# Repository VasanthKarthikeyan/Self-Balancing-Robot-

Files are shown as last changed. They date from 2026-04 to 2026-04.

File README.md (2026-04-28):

# Self-Balancing Robot (ESP32 + MPU6050 + TB6612FNG)

## Overview

This project is a **two-wheeled self-balancing robot** based on the classic **inverted pendulum system**. The robot continuously measures its tilt angle using an **MPU6050 IMU sensor** and applies real-time corrections through a **PID control algorithm** running on an **ESP32 microcontroller**.

By combining sensor fusion, motor control, embedded systems, and mechanical design, this project demonstrates practical implementation of real-time balancing robotics.

---

## Features

* Real-time self-balancing using PID control
* ESP32-based high-speed processing
* MPU6050 accelerometer + gyroscope sensor fusion
* Complementary filter for angle estimation
* TB6612FNG dual motor driver for efficient motor control
* PWM-based motor speed adjustment
* Custom 3D printed chassis design
* Battery-powered portable system
* Expandable for Bluetooth/Wi-Fi remote control

---

## Hardware Components

| Component | Description |
| --- | --- |
| ESP32 DevKit V1 | Main controller board |
| MPU6050 | IMU sensor for tilt measurement |
| TB6612FNG | Dual H-Bridge motor driver |
| N20 DC Gear Motors | Wheel actuation |
| HW-133A / LM2596 | Buck converter for voltage regulation |
| 18650 Li-ion Batteries | Power source |
| 3D Printed Chassis | Structural frame |

---

## System Architecture

### Workflow:

1. MPU6050 reads accelerometer and gyroscope data
2. Complementary filter estimates tilt angle
3. PID controller calculates correction
4. ESP32 generates PWM output
5. TB6612FNG drives motors
6. Wheels move to restore center of gravity

---

## Software Stack

* **Language:** C++ / Arduino Framework
* **Platform:** ESP32
* **Libraries:**

  * Wire.h
  * MPU6050 sensor communication
  * PWM motor control

---

## PID Control

The robot uses:

**PID Output = Kp × Error + Ki × Integral + Kd × Derivative**

### Parameters:

* **Kp** → Immediate correction
* **Ki** → Eliminates steady-state error
* **Kd** → Damping and stability

---

## Mechanical Design

* Fully custom **3D printed upper and lower chassis plates**
* Lightweight design for reduced motor load
* Optimized center of mass for improved balancing
* Modular mounting for electronics and batteries

---

## Challenges Faced

### Hardware:

* Short circuit in motor driver section
* Diagnosed using continuity testing
* Corrected wiring fault for proper motor functionality

### Software:

* Intermittent ESP32 COM port detection issues
* Flashing instability during code upload
* Required debugging of USB and board communication

---

## Future Improvements

* Wheel encoder integration
* Kalman filter implementation
* Bluetooth remote control
* Autonomous navigation
* LiDAR / ultrasonic obstacle detection
* Advanced control systems (LQR / adaptive PID)
* Mobile app integration

---

## Project Applications

* Robotics education
* Control systems experimentation
* Autonomous delivery systems
* Telepresence robots
* Embedded systems learning
* Advanced mechatronics projects

---

## Getting Started

### Requirements:

* Arduino IDE / PlatformIO
* ESP32 Board Package
* MPU6050 Library
* TB6612FNG Driver Wiring

### Steps:

1. Assemble chassis
2. Connect electronics as per schematic
3. Upload firmware to ESP32
4. Tune PID constants
5. Test balance carefully

---

## Results

* Successful motor actuation achieved
* Stable sensor fusion implemented
* Real-time balancing logic operational
* Mechanical prototype completed
* System serves as strong educational and engineering platform

---

## Author

**Vasanth Karthikeyan**
Mechatronics Engineering Student
Focused on robotics, embedded systems, and advanced prototyping.

---

## License

This project is open-source and available for educational and development purposes.

---

## Acknowledgment

This project represents practical integration of:

* Embedded systems
* Control theory
* Mechanical design
* Sensor fusion
* Real-time robotics engineering

It serves as a foundational step toward more advanced autonomous robotic systems.

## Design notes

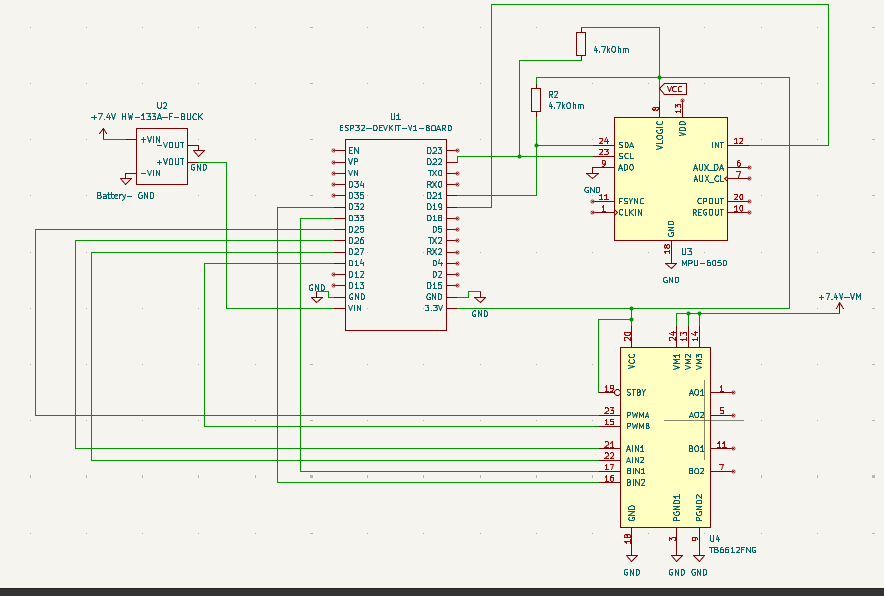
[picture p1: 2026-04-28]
botschematic.png

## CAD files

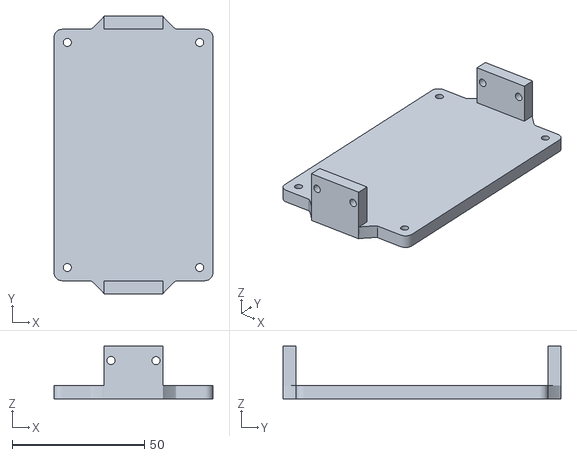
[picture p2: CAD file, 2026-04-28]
lower+body.stl
60.0 x 105.0 x 20.0

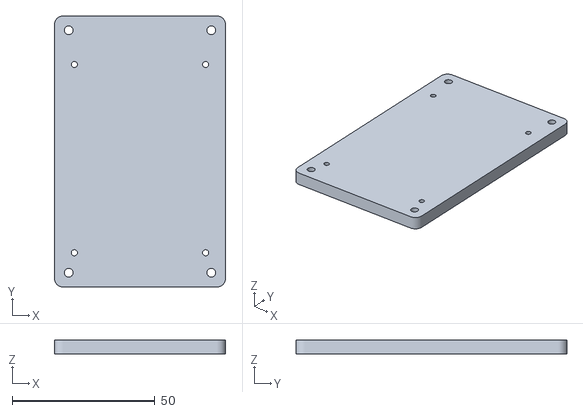
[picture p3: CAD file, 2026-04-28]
upper+body.stl
60.0 x 95.0 x 5.00

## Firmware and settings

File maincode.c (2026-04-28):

#include <Wire.h>

#define SDA_PIN  21
#define SCL_PIN  22
#define MPU_ADDR 0x68

#define ACCEL_SENS  16384.0f
#define GYRO_SENS   131.0f

float angle = 0.0f;
float alpha = 0.98f;
unsigned long lastTime = 0;
// PID
float Kp = 20.0f;
float Ki = 0.0f;
float Kd = 0.8f;
float setpoint   = 3.2f;  // change this to your upright angle
float pidError   = 0.0f;
float prevError  = 0.0f;
float integral   = 0.0f;
float pidOutput  = 0.0f;

// Offsets (calculated during calibration at startup)
float gyroXoffset  = 0.0f;
float accelXoffset = 0.0f;

void writeMPU(uint8_t reg, uint8_t val) {
  Wire.beginTransmission(MPU_ADDR);
  Wire.write(reg);
  Wire.write(val);
  Wire.endTransmission();
}
// Motor A
#define PWMA 25
#define AIN1 26
#define AIN2 27
// Motor B
#define PWMB 14
#define BIN1 33
#define BIN2 32

#define PWM_FREQ  20000
#define PWM_RES   8
#define DEADBAND  30
#define FALL_ANGLE 40.0f

void setMotorA(int spd) {
  if (spd > 0)      { digitalWrite(AIN1, HIGH); digitalWrite(AIN2, LOW); }
  else if (spd < 0) { digitalWrite(AIN1, LOW);  digitalWrite(AIN2, HIGH); spd = -spd; }
  else              { digitalWrite(AIN1, LOW);   digitalWrite(AIN2, LOW); }
  ledcWrite(PWMA, constrain(spd, 0, 255));
}

void setMotorB(int spd) {
  if (spd > 0)      { digitalWrite(BIN1, HIGH); digitalWrite(BIN2, LOW); }
  else if (spd < 0) { digitalWrite(BIN1, LOW);  digitalWrite(BIN2, HIGH); spd = -spd; }
  else              { digitalWrite(BIN1, LOW);   digitalWrite(BIN2, LOW); }
  ledcWrite(PWMB, constrain(spd, 0, 255));
}

void stopMotors() { setMotorA(0); setMotorB(0); }

void driveMotors(int out) {
  // Dead zone — motors don't move for tiny corrections
  if (abs(out) < DEADBAND) {
    stopMotors();
    return;
  }

  // Soft start — scale up from DEADBAND to 255
  // This prevents sudden jerks
  int pwm;
  if (out > 0) {
    pwm = map(out, DEADBAND, 255, 60, 255);
  } else {
    pwm = map(-out, DEADBAND, 255, 60, 255);
  }
  pwm = constrain(pwm, 0, 255);

  if (out > 0) {
    // Lean forward → drive forward to catch
    setMotorA(pwm);
    setMotorB(-pwm);  // B is physically reversed
  } else {
    // Lean backward → drive backward to catch
    setMotorA(-pwm);
    setMotorB(pwm);
  }
}

void readMPU(int16_t &ax, int16_t &ay, int16_t &az,
             int16_t &gx, int16_t &gy, int16_t &gz) {
  Wire.beginTransmission(MPU_ADDR);
  Wire.write(0x3B);
  Wire.endTransmission(false);
  Wire.requestFrom(MPU_ADDR, 14, true);
  ax = (Wire.read() << 8) | Wire.read();
  ay = (Wire.read() << 8) | Wire.read();
  az = (Wire.read() << 8) | Wire.read();
  Wire.read(); Wire.read(); // skip temp
  gx = (Wire.read() << 8) | Wire.read();
  gy = (Wire.read() << 8) | Wire.read();
  gz = (Wire.read() << 8) | Wire.read();
}

void setup() {
  Serial.begin(115200);
  pinMode(AIN1, OUTPUT); pinMode(AIN2, OUTPUT);
  pinMode(BIN1, OUTPUT); pinMode(BIN2, OUTPUT);
  ledcAttach(PWMA, PWM_FREQ, PWM_RES);
  ledcAttach(PWMB, PWM_FREQ, PWM_RES);
  stopMotors();
  delay(2000);

  // Pull-ups BEFORE Wire.begin
  pinMode(SDA_PIN, INPUT_PULLUP);
  pinMode(SCL_PIN, INPUT_PULLUP);
  Wire.begin(SDA_PIN, SCL_PIN);
  Wire.setClock(400000);

  // Wake up MPU
  writeMPU(0x6B, 0x00);
  delay(200);

  // Check if MPU is responding
  Wire.beginTransmission(MPU_ADDR);
  byte error = Wire.endTransmission();
  if (error != 0) {
    Serial.println("MPU6050 NOT FOUND - check wiring!");
    while (1);  // stop here
  }
  Serial.println("MPU6050 FOUND");

  // Calibrate - keep bot still
  Serial.println("Calibrating - keep perfectly still...");
  long sumGX = 0, sumAX = 0;
  int16_t ax, ay, az, gx, gy, gz;
  for (int i = 0; i < 500; i++) {
    readMPU(ax, ay, az, gx, gy, gz);
    sumGX += gx;
    sumAX += ax;
    delay(3);
  }
  gyroXoffset  = sumGX / 500.0f;
  accelXoffset = sumAX / 500.0f;
  Serial.print("Gyro offset: ");  Serial.println(gyroXoffset);
  Serial.print("Accel offset: "); Serial.println(accelXoffset);
  Serial.println("Calibration done - starting filter...");

  // Seed filter with accel angle
  readMPU(ax, ay, az, gx, gy, gz);
  float axf = (ax - accelXoffset) / ACCEL_SENS;
  float azf = az / ACCEL_SENS;
  angle = atan2(axf, azf) * 180.0f / PI;

  lastTime = micros();
}

void loop() {
  unsigned long now = micros();
  float dt = (now - lastTime) / 1000000.0f;
  lastTime = now;
  if (dt <= 0 || dt > 0.1f) dt = 0.01f;

  int16_t ax, ay, az, gx, gy, gz;
  readMPU(ax, ay, az, gx, gy, gz);

  float axf      = (ax - accelXoffset) / ACCEL_SENS;
  float azf      = az / ACCEL_SENS;
  float gyroRate = (gx - gyroXoffset) / GYRO_SENS;

  float accelAngle = atan2(axf, azf) * 180.0f / PI;
  angle = alpha * (angle + gyroRate * dt) + (1.0f - alpha) * accelAngle;

  // Safety
  if (fabs(angle) > FALL_ANGLE) {
    stopMotors();
    integral = 0.0f;
    Serial.print("FALLEN | angle: "); Serial.println(angle);
    delay(100);
    return;
  }

  // PID
  pidError   = angle - setpoint;
  integral  += pidError * dt;
  integral   = constrain(integral, -200.0f, 200.0f);
  float derivative = (pidError - prevError) / dt;
  prevError  = pidError;
  pidOutput  = Kp*pidError + Ki*integral + Kd*derivative;
  pidOutput  = constrain(pidOutput, -255.0f, 255.0f);

  driveMotors((int)pidOutput);

  Serial.print("Angle: ");  Serial.print(angle, 2);
  Serial.print(" | PID: "); Serial.print(pidOutput, 1);
  Serial.print(" | err: "); Serial.println(pidError, 2);

  delay(5); // 200Hz
}

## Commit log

2026-04-28 Add files via upload
    Added Schematic diagram of the project
2026-04-28 Add files via upload
    3d printed chassis for the project.
    [lower+body.stl, upper+body.stl]
2026-04-28 Add files via upload
    Code developed for ESP32 DEVKIT V1 using Arduino IDE
2026-04-28 Revise README for comprehensive project documentation
    Updated README to provide detailed project overview, features, hardware components, system architecture, software stack, PID control, mechanical design, challenges faced, future improvements, project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
